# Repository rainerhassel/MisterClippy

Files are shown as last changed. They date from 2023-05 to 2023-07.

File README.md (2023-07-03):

# MisterClippy

> Clipping Detector Module

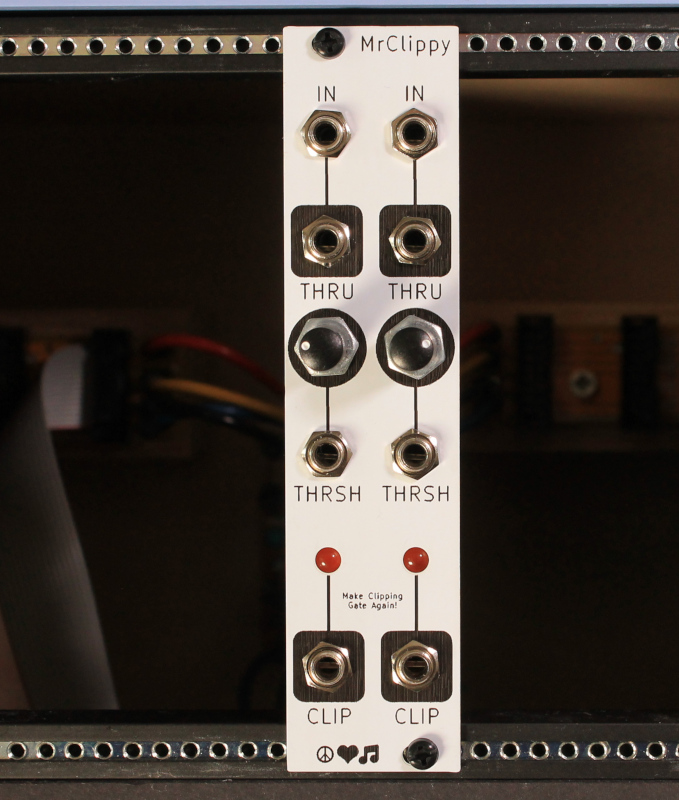
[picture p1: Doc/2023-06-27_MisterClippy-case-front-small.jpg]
Front view of the MisterClippy panel in a rack


## Dependencies

This project uses symbols from the [moPsy-KiCad-resources](https://github.com/moPsy-project/moPsy-KiCad-resources).

## License



This work is licensed under a [Creative Commons Attribution-ShareAlike 4.0 International License](http://creativecommons.org/licenses/by-sa/4.0/).

BY: Patrick Pickel (@rainerhassel) and Stefan Haun (@penguineer)

See [LICENSE.txt](LICENSE.txt) for details.

Using [moPsy-KiCad-resources](https://github.com/moPsy-project/moPsy-KiCad-resources) by Stefan Haun (mail@tuxathome.de).

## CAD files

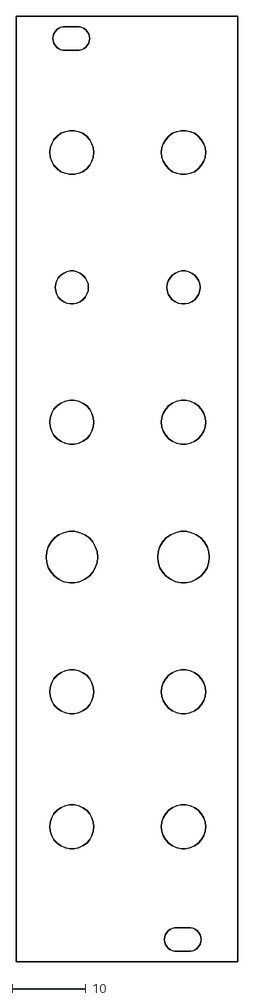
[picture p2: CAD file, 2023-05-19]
Panel/outline.dxf
30.2 x 128.5

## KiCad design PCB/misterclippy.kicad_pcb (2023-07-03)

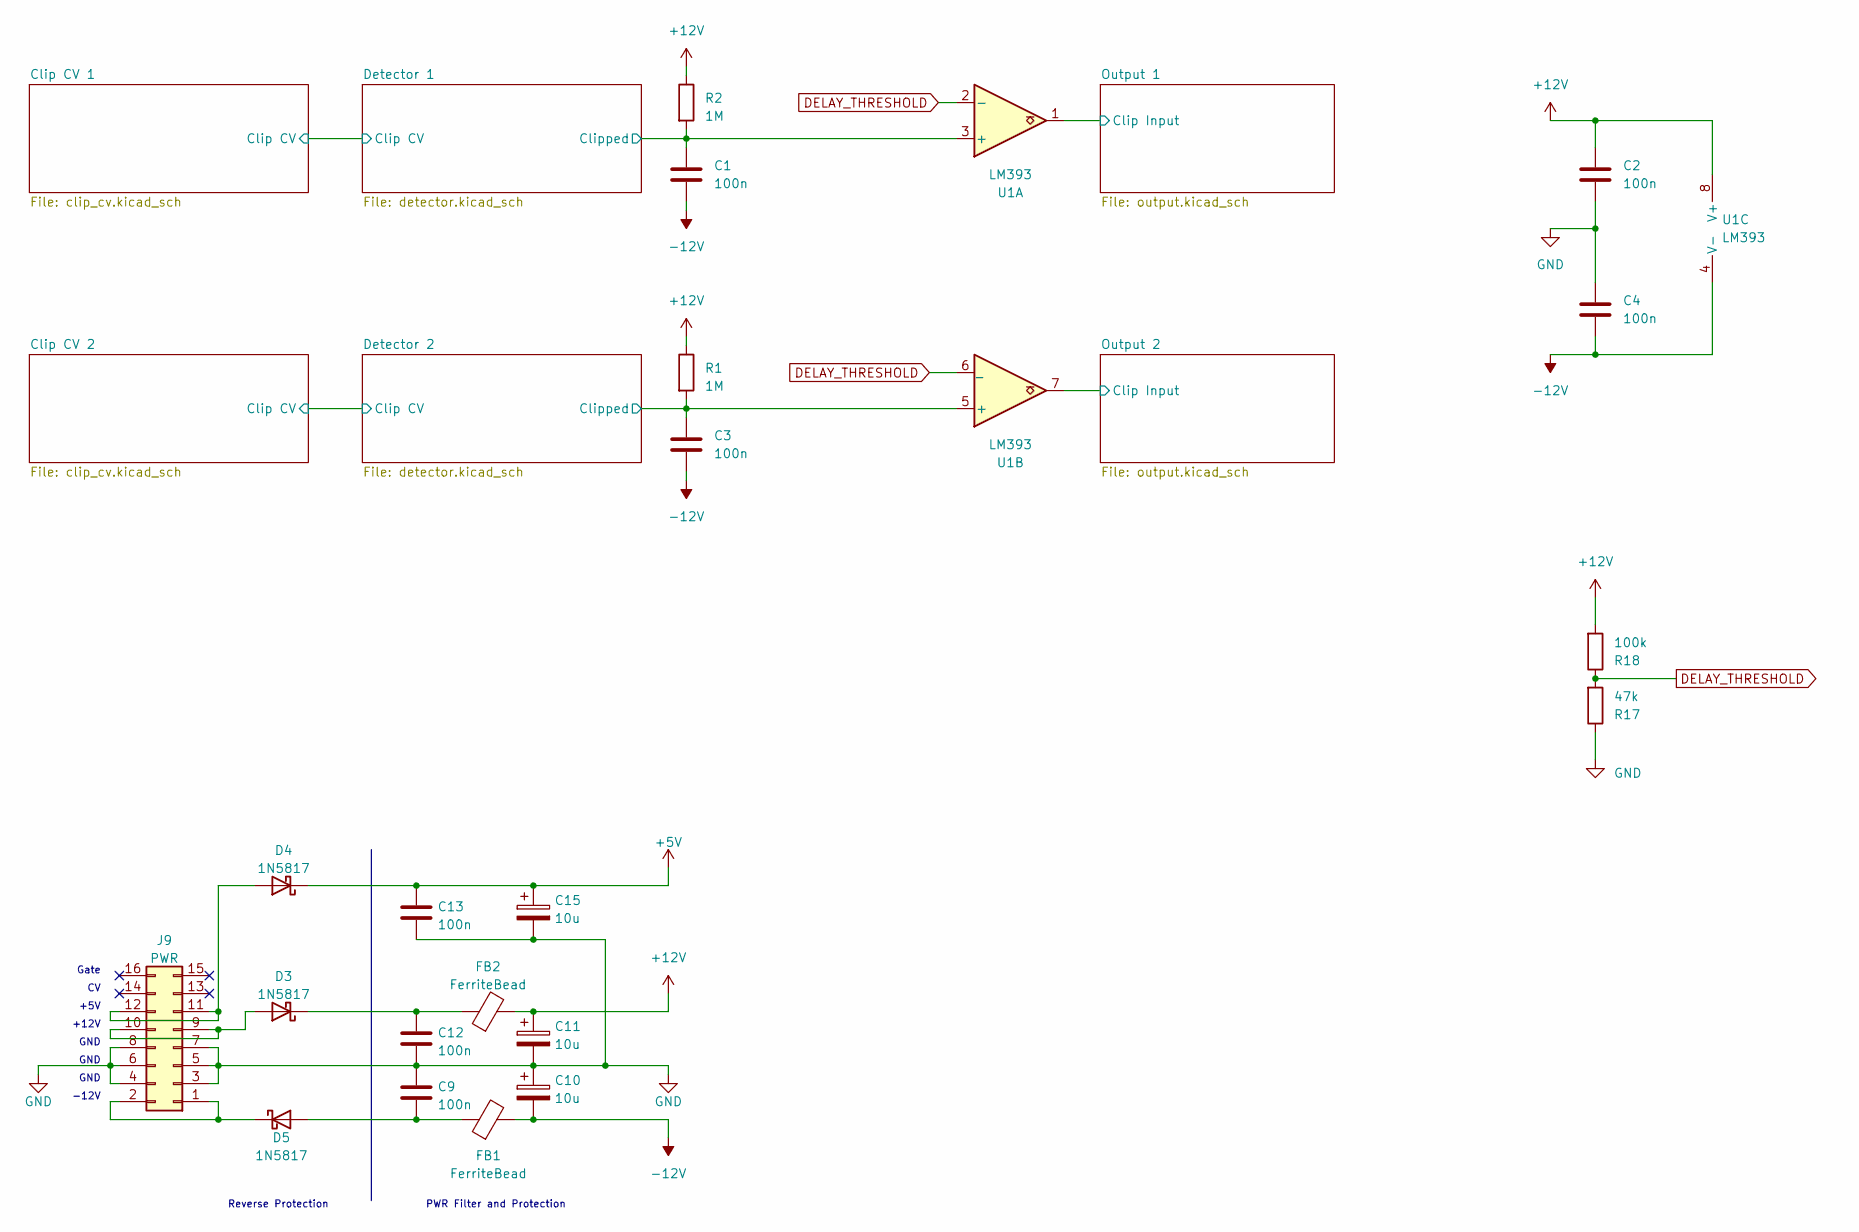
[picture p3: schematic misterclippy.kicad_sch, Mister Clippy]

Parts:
C1, C2, C3, C4, C9, C12, C13: 100n; C_Disc_D4.3mm_W1.9mm_P5.00mm
C10, C11, C15: 10u; CP_Radial_D4.0mm_P1.50mm
D3, D4, D5: 1N5817; D_DO-41_SOD81_P7.62mm_Horizontal
FB1, FB2: FerriteBead; FBeadL4D4
J9: PWR; PinHeader_2x08_P2.54mm_Vertical
R1, R2: 1M; R_Axial_DIN0207_L6.3mm_D2.5mm_P7.62mm_Horizontal
R17: 47k; R_Axial_DIN0207_L6.3mm_D2.5mm_P7.62mm_Horizontal
R18: 100k; R_Axial_DIN0207_L6.3mm_D2.5mm_P7.62mm_Horizontal
U1: LM393; DIP-8_W7.62mm

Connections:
+5V: C13.1, C15.1, D4.1 (K); also elsewhere on the board
+12V: C2.1, C11.1, FB2.2, R1.1, R2.1, R18.2, U1.8 (V+); also elsewhere on the board
-12V: C1.2, C3.2, C4.2, C10.2, FB1.2, U1.4 (V-); also elsewhere on the board
/Detector 1/Clipped: C1.1, R2.2, U1.3 (+); also elsewhere on the board
/Detector 2/Clipped: C3.1, R1.2, U1.5 (+); also elsewhere on the board
/Output 1/Clip Input: U1.1; also elsewhere on the board
/Output 2/Clip Input: U1.7; also elsewhere on the board
DELAY_THRESHOLD: R17.2, R18.1, U1.2 (-), U1.6 (_)
GND: C2.2, C4.1, C9.1, C10.1, C11.2, C12.2, C13.2, C15.2, J9.3, J9.4, J9.5, J9.6, J9.7, J9.8, R17.1; also elsewhere on the board
unnamed: D3.2 (A), J9.9, J9.10
unnamed: C12.1, D3.1 (K), FB2.1
unnamed: D4.2 (A), J9.11, J9.12
unnamed: C9.2, D5.2 (A), FB1.1
unnamed: D5.1 (K), J9.1, J9.2

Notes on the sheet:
Gate
GND
+12V
-12V
+5V
Reverse Protection
PWR Filter and Protection

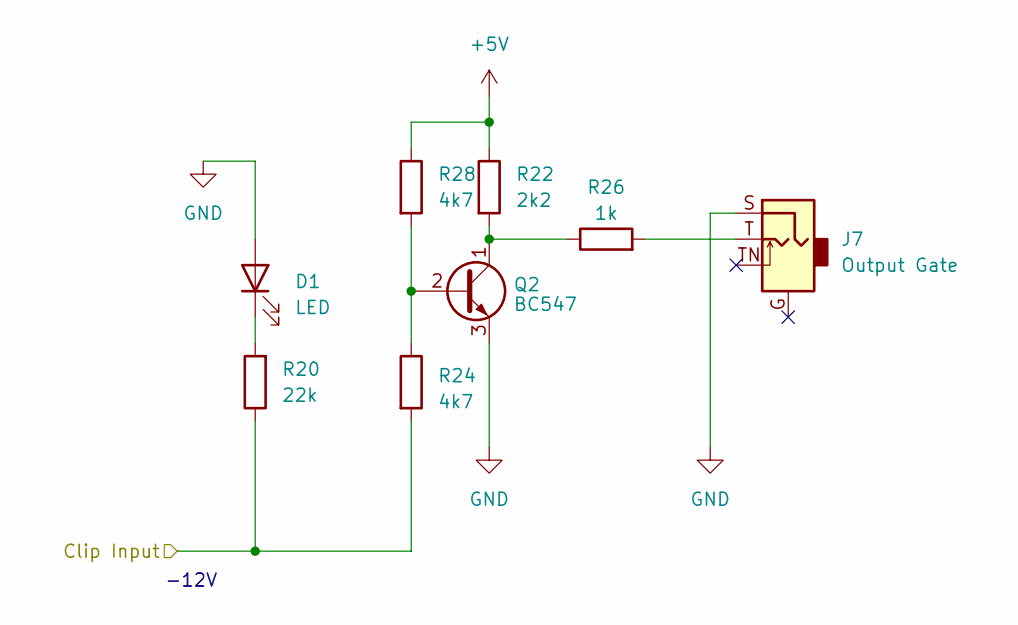
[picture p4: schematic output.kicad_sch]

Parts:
D1: LED; LED_D3.0mm
J7: Output Gate; Jack_3.5mm_QingPu_WQP-PJ398SM_Vertical_CircularHoles_Center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
Q2: BC547; TO-92_HandSolder
R20: 22k; R_Axial_DIN0207_L6.3mm_D2.5mm_P7.62mm_Horizontal
R22: 2k2; R_Axial_DIN0207_L6.3mm_D2.5mm_P7.62mm_Horizontal
R24, R28: 4k7; R_Axial_DIN0207_L6.3mm_D2.5mm_P7.62mm_Horizontal
R26: 1k; R_Axial_DIN0207_L6.3mm_D2.5mm_P7.62mm_Horizontal

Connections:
+5V: R22.1, R28.1; also elsewhere on the board
/Output 1/Clip Input: R20.1, R24.2; also elsewhere on the board
GND: D1.2 (A), J7.S, Q2.3 (E); also elsewhere on the board
unnamed: D1.1 (K), R20.2
unnamed: J7.T, R26.2
unnamed: Q2.2 (B), R24.1, R28.2
unnamed: Q2.1 (C), R22.2, R26.1

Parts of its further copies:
D2: LED; LED_D3.0mm
J8: Output Gate; Jack_3.5mm_QingPu_WQP-PJ398SM_Vertical_CircularHoles_Center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
Q1: BC547; TO-92_HandSolder
R19: 22k; R_Axial_DIN0207_L6.3mm_D2.5mm_P7.62mm_Horizontal
R21: 2k2; R_Axial_DIN0207_L6.3mm_D2.5mm_P7.62mm_Horizontal
R23, R27: 4k7; R_Axial_DIN0207_L6.3mm_D2.5mm_P7.62mm_Horizontal
R25: 1k; R_Axial_DIN0207_L6.3mm_D2.5mm_P7.62mm_Horizontal

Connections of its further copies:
+5V: R21.1, R27.1; also elsewhere on the board
/Output 2/Clip Input: R19.1, R23.2; also elsewhere on the board
GND: D2.2 (A), J8.S, Q1.3 (E); also elsewhere on the board
unnamed: D2.1 (K), R19.2
unnamed: J8.T, R25.2
unnamed: Q1.2 (B), R23.1, R27.2
unnamed: Q1.1 (C), R21.2, R25.1

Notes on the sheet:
-12V

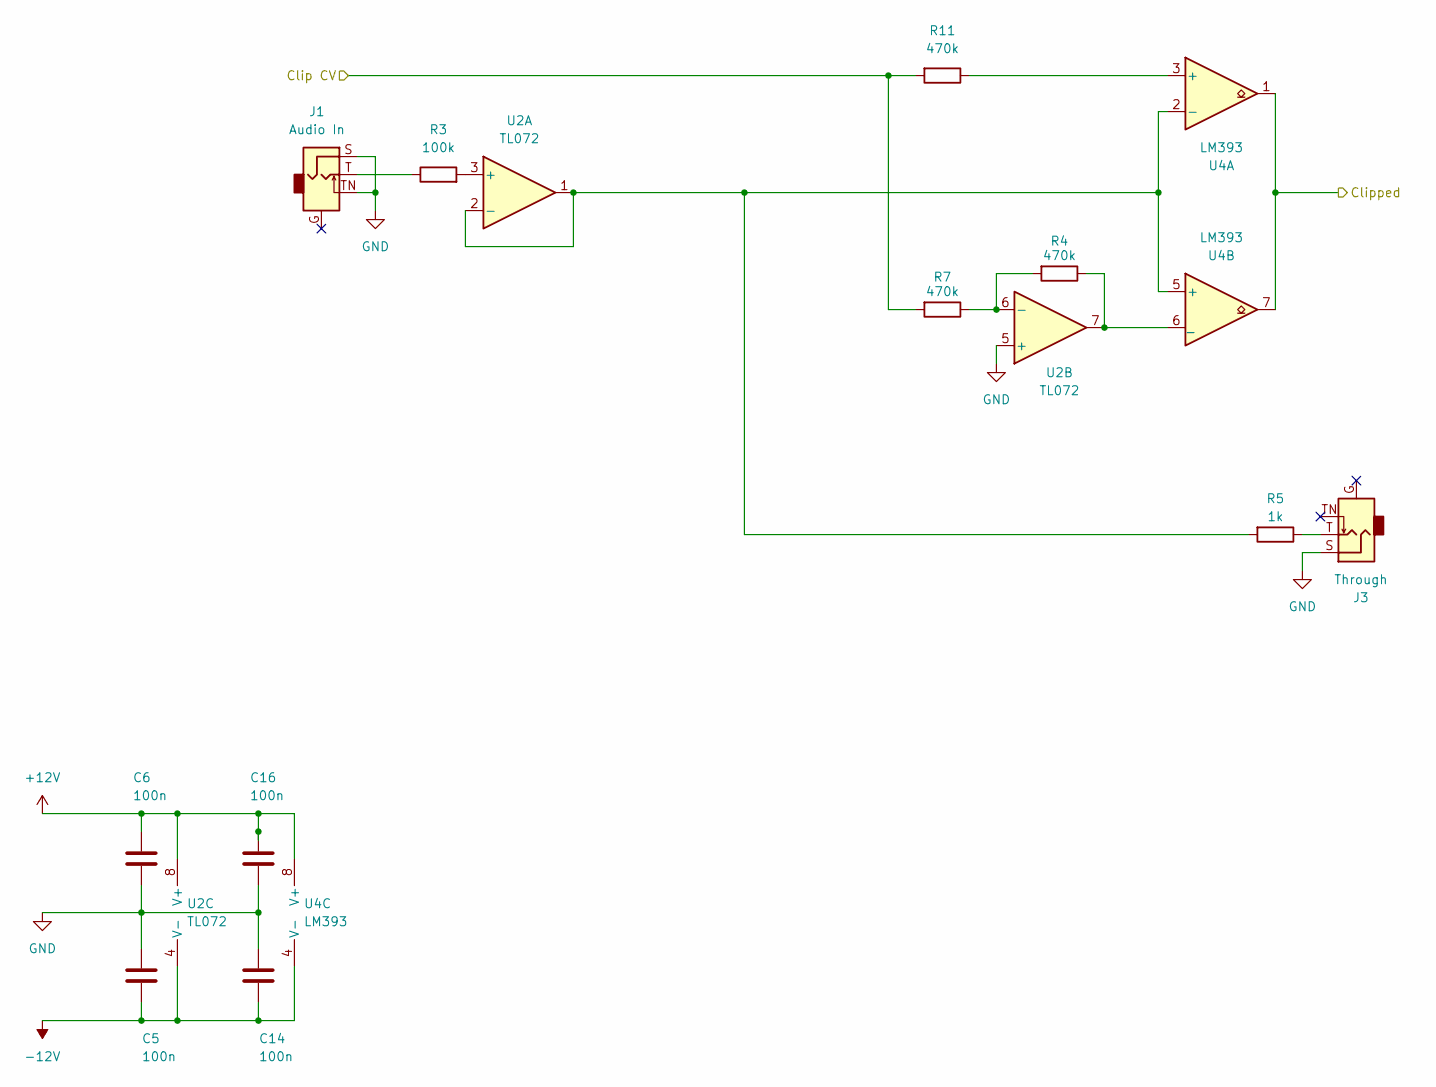
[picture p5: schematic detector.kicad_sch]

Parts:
C5, C6, C14, C16: 100n; C_Disc_D4.3mm_W1.9mm_P5.00mm
J1: Audio In; Jack_3.5mm_QingPu_WQP-PJ398SM_Vertical_CircularHoles_Center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
J3: Through; Jack_3.5mm_QingPu_WQP-PJ398SM_Vertical_CircularHoles_Center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
R3: 100k; R_Axial_DIN0207_L6.3mm_D2.5mm_P7.62mm_Horizontal
R4, R7, R11: 470k; R_Axial_DIN0207_L6.3mm_D2.5mm_P7.62mm_Horizontal
R5: 1k; R_Axial_DIN0207_L6.3mm_D2.5mm_P7.62mm_Horizontal
U2: TL072; DIP-8_W7.62mm
U4: LM393; DIP-8_W7.62mm

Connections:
+12V: C6.1, C16.1, U2.8 (V+), U4.8 (V+); also elsewhere on the board
-12V: C5.2, C14.2, U2.4 (V-), U4.4 (V-); also elsewhere on the board
/Clip CV 1/Clip CV: R7.2, R11.2; also elsewhere on the board
/Detector 1/Clipped: U4.1, U4.7; also elsewhere on the board
GND: C5.1, C6.2, C14.1, C16.2, J1.S, J1.TN, J3.S, U2.5 (+); also elsewhere on the board
unnamed: J1.T, R3.1
unnamed: J3.T, R5.1
unnamed: R3.2, U2.3 (+)
unnamed: R5.2, U2.1, U2.2 (-), U4.2 (-), U4.5 (+)
unnamed: R4.2, R7.1, U2.6 (-)
unnamed: R11.1, U4.3 (+)
unnamed: R4.1, U2.7, U4.6 (_)

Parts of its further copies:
C7, C8, C17, C18: 100n; C_Disc_D4.3mm_W1.9mm_P5.00mm
J2: Audio In; Jack_3.5mm_QingPu_WQP-PJ398SM_Vertical_CircularHoles_Center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
J4: Through; Jack_3.5mm_QingPu_WQP-PJ398SM_Vertical_CircularHoles_Center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
R6: 100k; R_Axial_DIN0207_L6.3mm_D2.5mm_P7.62mm_Horizontal
R8: 1k; R_Axial_DIN0207_L6.3mm_D2.5mm_P7.62mm_Horizontal
R9, R10, R12: 470k; R_Axial_DIN0207_L6.3mm_D2.5mm_P7.62mm_Horizontal
U3: TL072; DIP-8_W7.62mm
U5: LM393; DIP-8_W7.62mm

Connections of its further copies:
+12V: C7.1, C18.1, U3.8 (V+), U5.8 (V+); also elsewhere on the board
-12V: C8.2, C17.2, U3.4 (V-), U5.4 (V-); also elsewhere on the board
/Clip CV 2/Clip CV: R10.2, R12.2; also elsewhere on the board
/Detector 2/Clipped: U5.1, U5.7; also elsewhere on the board
GND: C7.2, C8.1, C17.1, C18.2, J2.S, J2.TN, J4.S, U3.5 (+); also elsewhere on the board
unnamed: J2.T, R6.1
unnamed: J4.T, R8.1
unnamed: R6.2, U3.3 (+)
unnamed: R8.2, U3.1, U3.2 (-), U5.2 (-), U5.5 (+)
unnamed: R9.2, R10.1, U3.6 (-)
unnamed: R12.1, U5.3 (+)
unnamed: R9.1, U3.7, U5.6 (_)

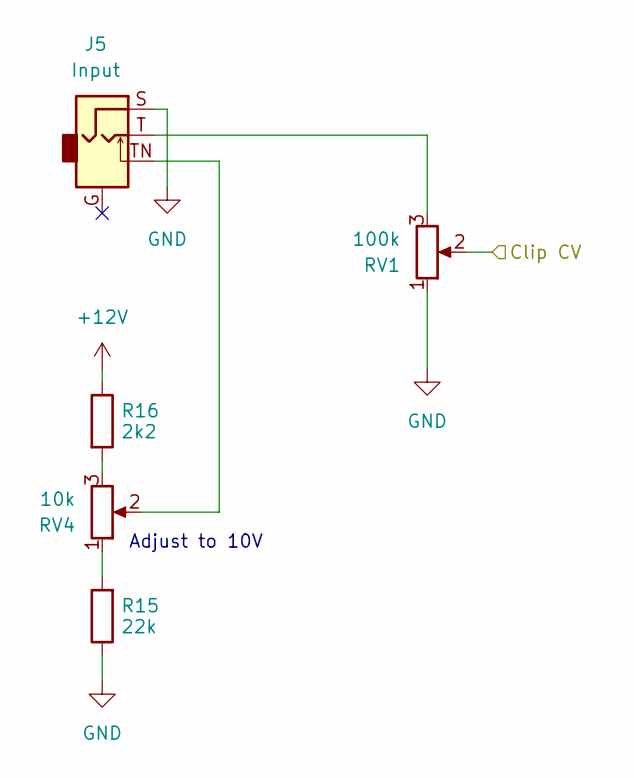
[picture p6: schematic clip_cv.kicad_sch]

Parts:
J5: Input; Jack_3.5mm_QingPu_WQP-PJ398SM_Vertical_CircularHoles_Center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
R15: 22k; R_Axial_DIN0207_L6.3mm_D2.5mm_P7.62mm_Horizontal
R16: 2k2; R_Axial_DIN0207_L6.3mm_D2.5mm_P7.62mm_Horizontal
RV1: 100k; Potentiometer_Befaco_12mm_Single_Vertical
RV4: 10k; Potentiometer_Piher_PT-10-V10_Vertical

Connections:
+12V: R16.1; also elsewhere on the board
/Clip CV 1/Clip CV: RV1.2; also elsewhere on the board
GND: J5.S, R15.1, RV1.1; also elsewhere on the board
unnamed: J5.T, RV1.3
unnamed: J5.TN, RV4.2
unnamed: R15.2, RV4.1
unnamed: R16.2, RV4.3

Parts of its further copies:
J6: Input; Jack_3.5mm_QingPu_WQP-PJ398SM_Vertical_CircularHoles_Center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
R13: 22k; R_Axial_DIN0207_L6.3mm_D2.5mm_P7.62mm_Horizontal
R14: 2k2; R_Axial_DIN0207_L6.3mm_D2.5mm_P7.62mm_Horizontal
RV2: 100k; Potentiometer_Befaco_12mm_Single_Vertical
RV3: 10k; Potentiometer_Piher_PT-10-V10_Vertical

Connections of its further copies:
+12V: R14.1; also elsewhere on the board
/Clip CV 2/Clip CV: RV2.2; also elsewhere on the board
GND: J6.S, R13.1, RV2.1; also elsewhere on the board
unnamed: J6.T, RV2.3
unnamed: J6.TN, RV3.2
unnamed: R13.2, RV3.1
unnamed: R14.2, RV3.3

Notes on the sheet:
Adjust to 10V

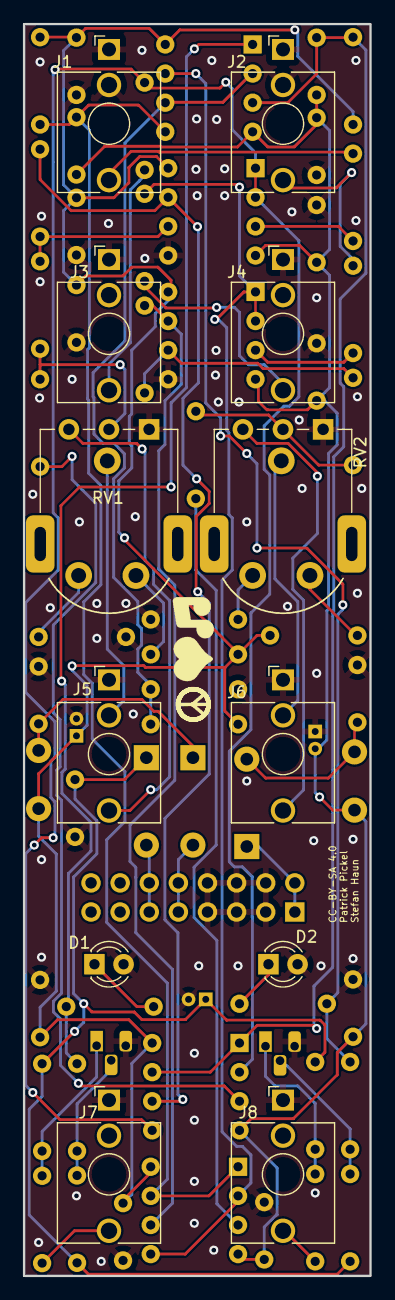
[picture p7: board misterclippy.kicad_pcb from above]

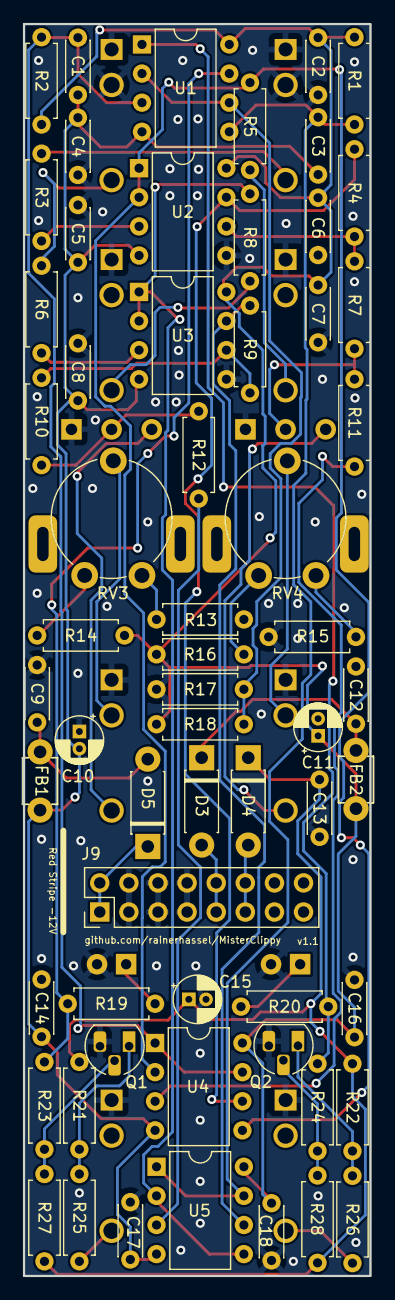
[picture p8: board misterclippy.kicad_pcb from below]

Board: 2 copper layers, 30.2 x 109.2 mm, 73 parts (61 on the bottom side), 46 nets.

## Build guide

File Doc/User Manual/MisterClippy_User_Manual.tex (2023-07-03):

\documentclass[a4paper,
               11pt,
               parskip=half,
               headinclude,
               titlepage=false]{scrartcl}

%%%%%%%%%%%%%%%%%%%%%%%%%%%%%%%%%%%%%%%%
\newcommand{\metaauthor}{moPsy}
\newcommand{\metatitle}{MisterClippy User Manual}
\newcommand{\metarev}{1.1}
%%%%%%%%%%%%%%%%%%%%%%%%%%%%%%%%%%%%%%%%

\usepackage[utf8]{inputenc}

\usepackage[T1]{fontenc}        % Tries to use Postscript Type 1 Fonts for better rendering
\usepackage{lmodern}            % Provides the Latin Modern Font which offers more glyphs than the default Computer Modern
\usepackage[sfdefault]{carlito}
\usepackage[intlimits]{amsmath} % Provides all mathematical commands
\usepackage[protrusion=true,
            expansion,
            kerning=true,
            babel=true]{microtype}
\usepackage{fontawesome}

\usepackage[english]{babel}
\usepackage[english]{isodate}

\usepackage{eurosym}
\usepackage[shortlabels]{enumitem}

\usepackage{grffile}            % Allow you to include images (like graphicx). Usage: \includegraphics{path/to/file}

\usepackage[ugly]{units}        % Allows you to type units with correct spacing and font style. Usage: $\unit[100]{m}$ or $\unitfrac[100]{m}{s}$

\usepackage{xspace}             % Use \xpsace in macros to automatically insert space based on context. Usage: \newcommand{\es}{ESPResSo\xspace}
\usepackage[dvipsnames,table]{xcolor}             % Obviously colors. Usage: \color{red} Red text
\usepackage{booktabs}           % Nice rules for tables. Usage \begin{tabular}\toprule ... \midrule ... \bottomrule

%\usepackage[hang]{subfigure}  % unterteilte Abbildungen
\usepackage{setspace}          %fuer dem Zeilanabstand
\usepackage[hang,bf,footnotesize]{caption}   % bessere Bildunterschriften
\usepackage{wrapfig}

\usepackage{csquotes}

\usepackage[hyphens]{url}                % Lets you typeset urls. Usage: \url{http://...}
\usepackage[pdftex,colorlinks=true,linkcolor=black,citecolor=black,urlcolor=black]{hyperref}
\hypersetup{
  pdftitle    = {\metatitle},
  pdfsubject  = {Assembly Guide},
  pdfauthor   = {\metaauthor},
  pdfkeywords = {} ,
  pdfcreator  = {pdflatex},
  pdfproducer = {LaTeX with hyperref}
}
%%%%%%%%%%%%%%%%%%%%%%%%%%%%%%%%%%%%%%%%

\usepackage{pdfpages}

\usepackage{tabularx}

\usepackage[headsepline, footsepline]{scrlayer-scrpage}
\setlength{\headheight}{34pt} % logo height
\clearpairofpagestyles
\ohead{
\vfill%
\begin{tabular}{@{}l l@{}}
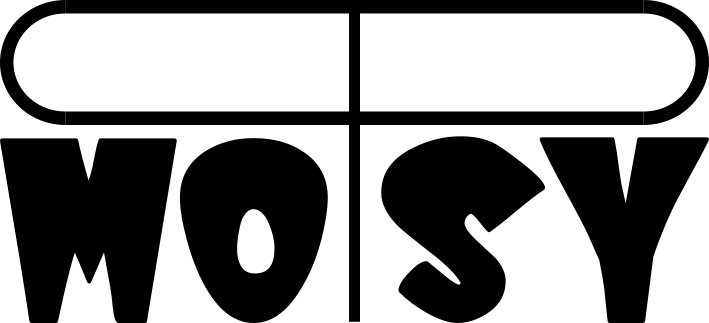
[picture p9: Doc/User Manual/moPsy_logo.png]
Patrick with \hspace*{-0.1cm}
\end{tabular}
}
\ihead{
\vfill%
{\huge MisterClippy} \,v\metarev\, User Manual%
}
\ofoot{Page \thepage}
\setkomafont{pageheadfoot}{\sffamily\footnotesize}
\setkomafont{pagination}{}
\pagestyle{scrheadings}

%\usepackage{background}

%\usepackage[section]{placeins} % keep figures in their section

\definecolor{level_easy}{rgb}{0.2, 0.6, 0.1}

\definecolor{row1}{rgb}{1.0, 1.0, 1.0}
\definecolor{row2}{rgb}{0.93, 0.93, 0.99}

\begin{document}

\begin{minipage}[]{11cm}
\setlength{\parskip}{\medskipamount}
\section*{Thank you for choosing the MisterClippy module!}

This manual provides information on installing and using the MisterClippy module.
We hope that all questions will be answered.

If you encounter a problem or have further questions,
please do not hesitate to reach out to us at \href{mailto:contact@mopsy-music.de}{\texttt{contact@mopsy-music.de}}.

\vspace{1em}
\begin{center}
Enjoy your module! \quad 
\end{center}

\section*{About MisterClippy}

MisterClippy is a clip detector with adjustable threshold and gate output.
And since this is so much fun, we have doubled the feature set in one module!

\end{minipage}%
\hspace{0.5cm}
\begin{minipage}[]{3.5cm}
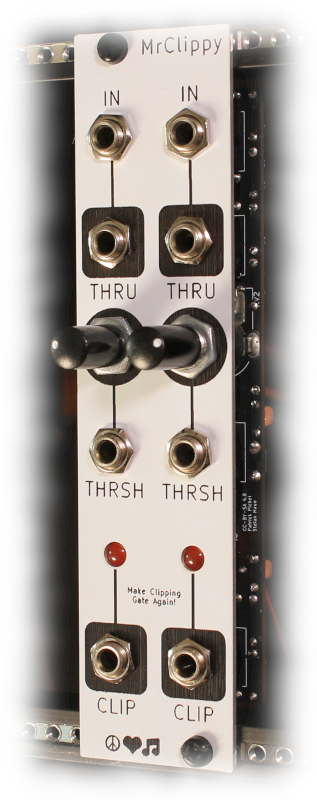
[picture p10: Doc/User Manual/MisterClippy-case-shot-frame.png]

\end{minipage}

\section*{Installation}

The MisterClippy module will occupy \textbf{\unit[12]{HP}} in your rack with a depth of \textbf{\unit[20]{mm}}.

To \textbf{connect power} …
\begin{enumerate}
 \item Please make sure that your cabinet is \textbf{disconnected from the mains} and has no power.
 \item The module is connected with a \textbf{16-pin} (2x8) bus cable.
 \item \textbf{Check your power cable and the polarity.} The coloured ({\color{red}red}) line on the cable (pin 1) needs to be connected to the \textbf{\unit[-12]{V}} rail.
 If the module is installed in an upright orientation, the \textbf{\color{red}red stripe} needs to be \textbf{facing down}.
 \item If you plug the module backwards, it may burn out.
 Unfortunately this cannot be covered by the warranty.
\end{enumerate}

%The module draws a maximum of \textbf{\unit[40]mA} from the \textbf{\unit[+12]{V}} rail.
\emph{Detailed power measurements are pending.}

\begin{minipage}[]{4cm}
\vspace{-2cm}
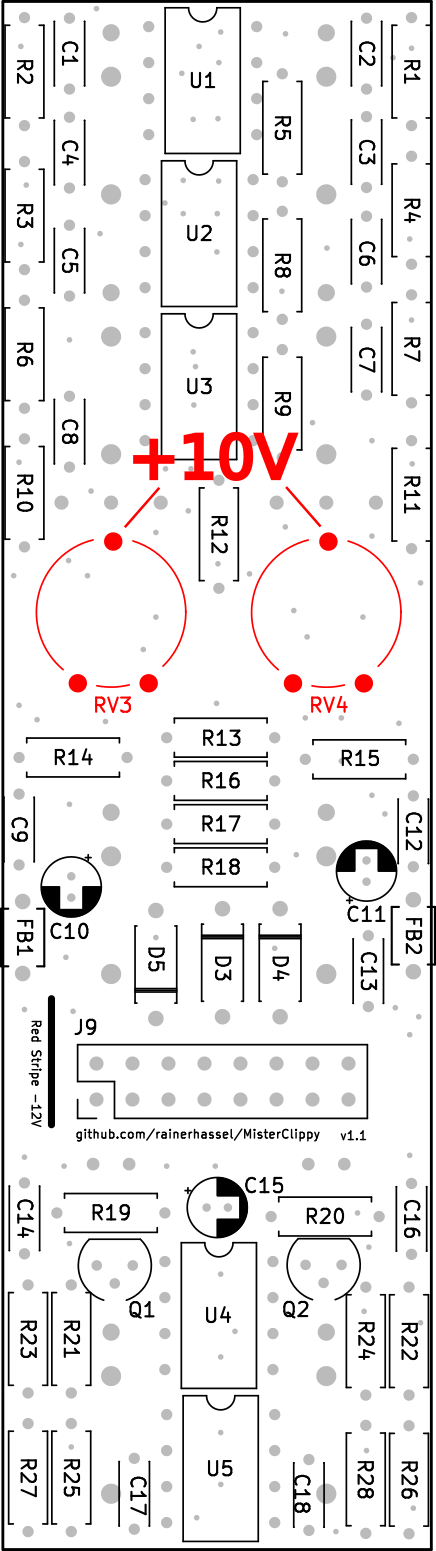
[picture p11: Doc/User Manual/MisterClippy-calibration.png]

\end{minipage}
\hspace{0.5cm}
\begin{minipage}[b]{10.5cm}
\setlength{\parskip}{\medskipamount}

\section*{Calibration}

The module has two trim potentiometers, \textbf{\color{red}RV3} and \textbf{\color{red}RV4}, to adjust the default clip detection threshold.
These should be set so that their middle pin presents \textbf{\unit[+10]{V}} with respect to ground.

\end{minipage}

\begin{minipage}[]{11cm}
\setlength{\parskip}{\medskipamount}
\section*{Frontpanel}

The module is divided into two equal and independent sections.

The \textbf{(audio) signal} is fed into the input \textbf{\color{red}IN} (1).

As this signal is usually needed somewhere else, it is \textbf{mirrored} to the output \textbf{\color{red}THRU} (2) without modification.

\vspace{1em}

The \textbf{clip threshold} can be provided as a CV on the \textbf{\color{red}THRSH} input (4) and \textbf{defaults to \unit[+10]{V}}.

In addition, the clip threshold---internal or externally provided---can be \textbf{attenuated} with the potentiometers (3).

\vspace{1em}

Clipping is \textbf{detected} if the signal is \textbf{above} the clip threshold \textbf{or below} the negated clip threshold.
For example, with a clip threshold of \unit[+4]{V}, any voltage greater then \unit[+4]{V} and lower than \unit[-4]{V} will be detected as clipping.

If clipping is detected, the \textbf{\color{red}LED} (5) will light up and a \textbf{gate} is presented at the \textbf{\color{red}CLIP} output (6).

Note that the clip signal will \textbf{persist} for a short time. If another clipping occurs withing this time window, the gate will be \textbf{extended} instead of being re-triggered.

\end{minipage}%
\hspace{0.5cm}
\begin{minipage}[]{3.5cm}
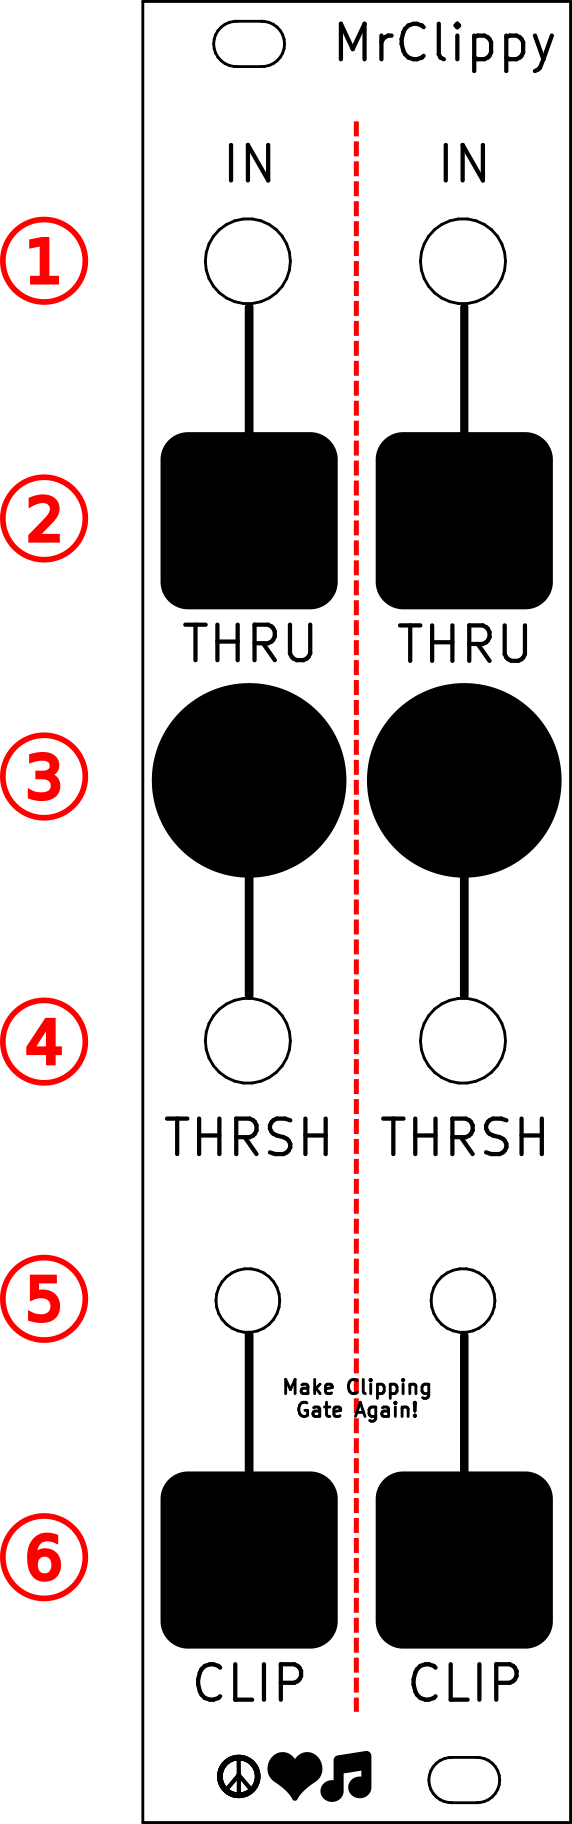
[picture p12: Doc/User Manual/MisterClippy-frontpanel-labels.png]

\end{minipage}

\section*{Online Resources}

More about the module  …
\begin{itemize}[noitemsep]
 \item on GitHub: \url{https://github.com/rainerhassel/MisterClippy}
 \item via e-mail: \href{mailto:contact@mopsy-music.de}{\texttt{contact@mopsy-music.de}}
\end{itemize}

\end{document}

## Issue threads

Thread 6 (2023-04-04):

:bug: 1M potentiometer footprints do not fit

penguineer, 2023-04-04:
After https://github.com/moPsy-project/moPsy-KiCad-resources/issues/13 fix the 1M pot footprints.

Closed 2023-06-05.

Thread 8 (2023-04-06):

:bug: Module v1 does not behave as intended

penguineer, 2023-04-06:
# Observations from my tests

## What works

* Power consumption seems as intended.
* Nothing smoked or blew up.
* Audio thru works.
* If clipping is detected, the respective LED lights up and the Clip Gate is active.
* The Clip CV attenuator influences the clip threshold.
* There is some kind of clip detection.

## What does not work

* It seems that the clip detection needs a negative threshold to do anything at all.
* Clipping is detected when the signal is _inside_ the window, instead of _outside_ the window.
* The default threshold can be set only to 9V instead of 10V - resistors need to be adjusted.

penguineer, 2023-06-05:
These issues have been fixed with v1.1

Closed 2023-06-05.

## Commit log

2023-03-12 add .gitignore for kicad
2023-03-12 initial schematic commit
    [clip_cv.kicad_sch, detector.kicad_sch, misterclippy.kicad_pcb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]
2023-03-12 :art: Improve layout/positioning on main sheet
    Also condense the voltage divider for the clip delay threshold,
    as there is no load on this part and it can be shared between buffers.
    [clip_cv.kicad_sch, detector.kicad_sch, misterclippy.kicad_sch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]
2023-03-12 :art: Adjust layout of Clip CV input
    [clip_cv.kicad_sch, output.kicad_sch]
2023-03-12 :bug: Rearrange detector and replace global label
    Global labels in hierarchical sheets lead to connected traces, as the
    label will be connected by name globally.
    Replaced the global label in "Detector" by a wire.
    [detector.kicad_sch]
2023-03-12 :wrench: Re-assign component designators
    [clip_cv.kicad_sch, detector.kicad_sch, misterclippy.kicad_pcb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]
2023-03-12 :wrench: Replace audio jack footprints by centered versions
    [clip_cv.kicad_sch, detector.kicad_sch, output.kicad_sch]
2023-03-12 PCB layout ready for production
    [detector.kicad_sch, misterclippy.kicad_pcb]
2023-03-13 :art: Try for a design where ICs do not cover jacks
    [detector.kicad_sch, misterclippy.kicad_pcb, misterclippy.kicad_sch]
2023-03-13 :art: Turn poti direction around
    Make sure that turning the poti clockwise increases the setting.
    [clip_cv.kicad_sch]
2023-03-13 :hammer: Adapt PCB to fixed poti directions
    [misterclippy.kicad_pcb]
2023-04-04 :pencil2: Replace Befaco 12mm poti footprint with fixed verion
    Use footprint based on https://github.com/moPsy-project/moPsy-KiCad-resources/pull/14
    and adjust traces accordingly
    [misterclippy.kicad_pcb]
2023-05-18 fix schematics after further testing
    [detector.kicad_sch, misterclippy.kicad_sch, output.kicad_sch]
2023-05-18 Adapt PCB to fixed schematic
    [misterclippy.kicad_pcb]
2023-05-18 Bump PCB revision number to v1.1
    [misterclippy.kicad_pcb]
2023-05-18 add panel outline.dxf
    [outline.dxf]
2023-05-18 Add gitignore for KiCAD project
2023-05-18 Add frontpanel PCB
    [Panel.kicad_pcb]
2023-05-19 :sparkles: Add text "Make Clipping Gate Again" to panel
    Idea by Patrick! :)
    [Panel.kicad_pcb]
2023-05-20 :art: Apply geographical reannotation
    [clip_cv.kicad_sch, detector.kicad_sch, misterclippy.kicad_pcb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]
2023-05-20 :art: Change transistor footprint for hand soldering
    [misterclippy.kicad_pcb, output.kicad_sch]
2023-06-05 :art: Adjust voltage divider for Clip CV tap
    Adjust the voltage divider so that 10V are within a good
    adjustment range.
    [clip_cv.kicad_sch]
2023-06-05 :wrench: Update resistor value in PCB
    [misterclippy.kicad_pcb]
2023-06-07 :wrench: Adjust the voltage dividers for Clip CV
    [clip_cv.kicad_sch, detector.kicad_sch]
2023-06-07 :wrench: Transfer new resistor values to PCB
    [misterclippy.kicad_pcb]
2023-06-26 :bento: Add case shot picture
2023-06-26 :bento: Add figure for calibration
2023-06-28 :bento: Add MisterClippy case shot
2023-06-28 :memo: Add case shot picture to README
2023-07-02 :pencil2: Fix name on CC label
    [misterclippy.kicad_pcb]

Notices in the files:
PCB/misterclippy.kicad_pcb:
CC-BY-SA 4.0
